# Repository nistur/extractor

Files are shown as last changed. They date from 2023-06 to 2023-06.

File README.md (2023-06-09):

Extractor
=========

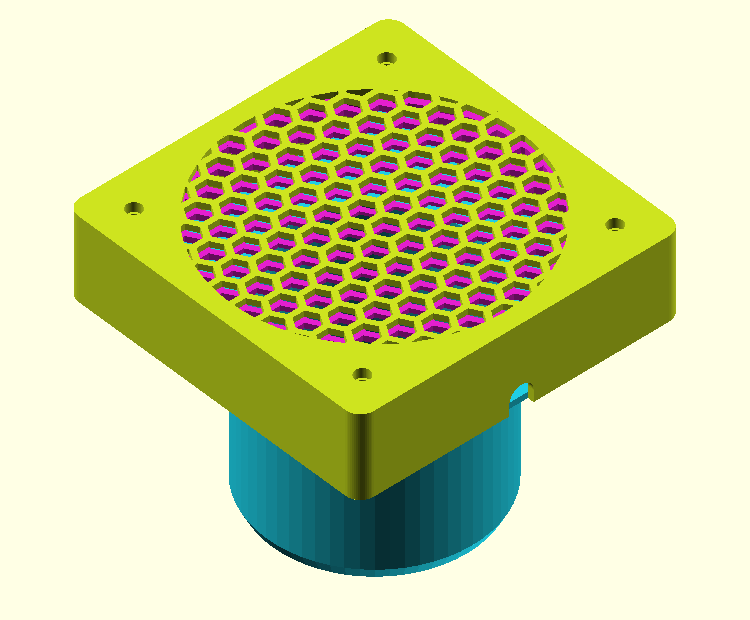
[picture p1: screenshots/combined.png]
Extractor Fan Enclosure


I have an enclosure for my 3D printer, but it still smells, I want to be able to safely vent this outside. I have a bunch of 120mm PC fans around, and a 12V power supply, so I thought I'd quickly make an enclosure to hold this, and connect to an exhaust pipe made from a drain pipe.

The enclosure is being designed to be used with a 120x25mm PC style fan, and a 90mm ID pipe for exhaust. It has space for a carbon filter to be cut and put at the front. All dimensions should be in modifiable in params.scad for other size parts. I have not added a HEPA filter at this point because everything I can find is a specific size for a specific vacuum cleaner etc, and not a simple cut-the-right-size filter sheet like a carbon filter. Assuming this works, I will look for a solution for this.

All models are created in modules/mod_{MODULE}.scad and then are imported into {MODULE}.scad for exporting as STL in the correct orientation. A Makefile is provided for easy export on Linux. To see the extractor built, preview.scad has been provided with the parts in the correct position.

NOTE: This model is incomplete and has not been test printed yet. It is also still final measurement/confirmation on all dimensions.

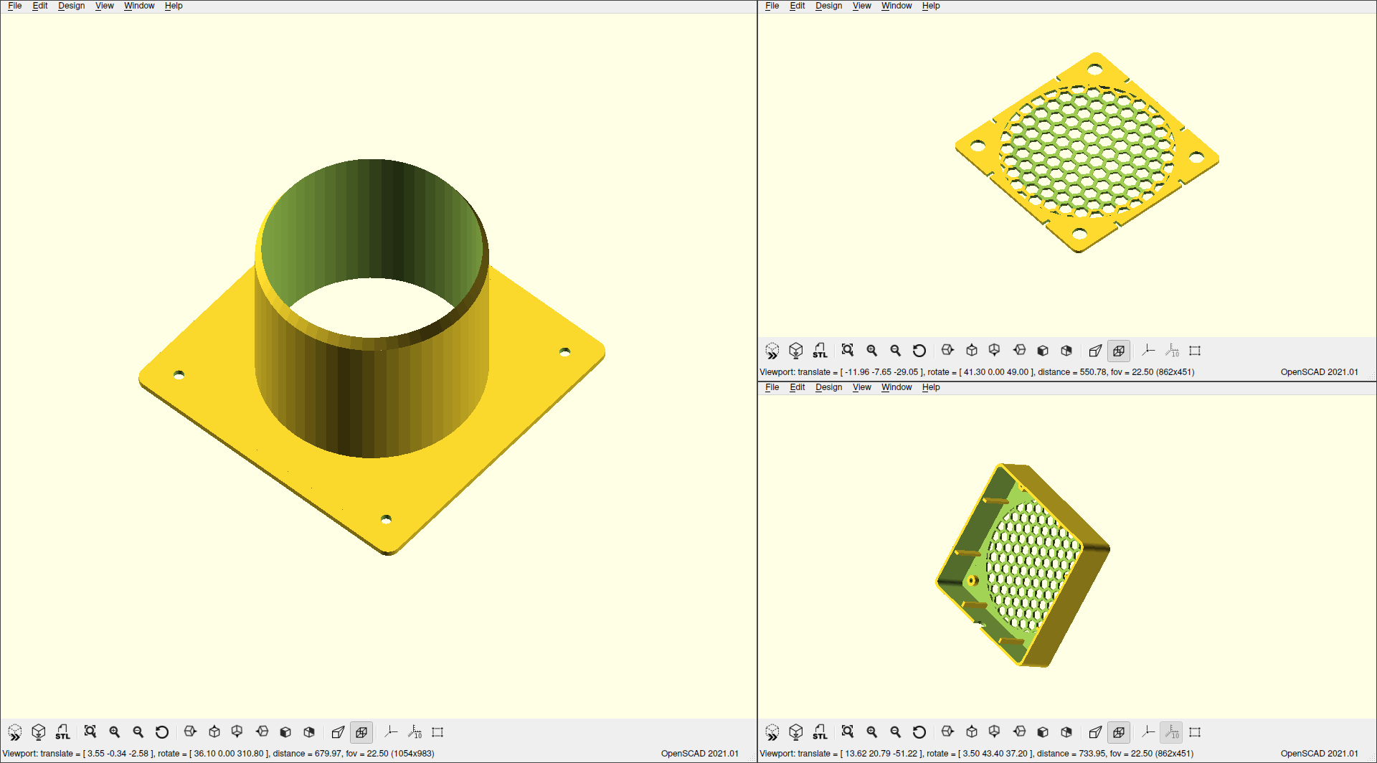
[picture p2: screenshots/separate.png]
Parts


To mount this, the intention is to cut/drill a 100mm diameter hole in the enclosure, and then insert threaded inserts into the enclosure (or tap if the enclosure can take machine threads) based on the hole pattern for the fan used, in the case of a 120mm fan, this is 105mm apart. Then a long screw is interted through all parts, sandwiching a carbon filter between the enclosure and the filterguard, with the slightly concave side facing the fan. The screws are then only screwed into the threaded inserts and not into the printed parts, reducing wear on those parts. A suitable exhaust pipe is then fitted over the connector which should be protruding out of the hole.

I have also created an "exhaust" part, which is a matching part that I will be attaching the where it will be finally exhausting outside. This is similar to the "connector" part, but with the opposite type connector (ie it goes over a 90mm pipe rather than inside an end piece) and includes a grille to keep out leaves or whatever happens to be trying to get in.

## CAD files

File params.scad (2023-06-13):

/*
 * Copyright (c) 2023 Philipp Geyer
 *
 * This software is provided 'as-is', without any express or implied warranty. In no
 * event will the authors be held liable for any damages arising from the use of this
 * software.
 *
 * Permission is granted to anyone to use this software for any purpose, including
 * commercial applications, and to alter it and redistribute it freely, subject to the
 * following restrictions:
 *
 * 1. The origin of this software must not be misrepresented; you must not claim
 *    that you wrote the original software. If you use this software in a product,
 *    an acknowledgment in the product documentation would be appreciated
 *    but is not required.
 * 2. Altered source versions must be plainly marked as such, and must not be
 *    misrepresented as being the original software.
 * 3. This notice may not be removed or altered from any source distribution.
 *
 * Philipp Geyer
 * nistur@gmail.com
 */

// Size of the fan - This is the outside dimentions, and assumes a square. For a standard PC fan,
// this is correct at 120mm
fan_size=120;

// Thickness of the fan. This is dependant on the make and model fan you have. Could be 25mm, 38mm etc
fan_thickness=25;

// Thickness of the carbon filter - this is currently including one `thickness` below to account for the
// guard piece. I didn't want to split this up, as I was considering the guard and the filter as one unit
filter_thickness=5;

// Space around the fan for routing wires etc
padding=5;

// How curvy do we want this. 5mm gives a nice look
corner_radius=5;

// Thickness of the walls of the enclosure.
thickness=2.5;

// Inside diameter of the connector - this is not critical as it doesn't interface with anything (yet) however does
// implicitly define the outer diameter of the exhaust sleeve, which keeps the same wall thickness as the connector.
// Note: Should this be entirely derived from `thickness`? It would currently work out to be the same, but originally
// kept separate so that I could make the connector wall thicker if I needed more strength.
connector_id=85;

// Outside diameter of the connector - This is important as it interfaces with the inside of the pipe
connector_od=90;

// Length of the connector - how much is able to fit inside the exhaust pipe
connector_length=80;

// How long a taper we want to put on the top of the connector, to allow for easier fitting
connector_taperlength=10;

// How much the taper should cut in by
connector_taperamount=5;

// Length of the exhaust pipe. Mirrors `connector_length` above but kept separate as it is probably
// desirable to be different
exhaust_length=50;

// Diameter of screws used to mount this. I wanted to use M4, but added a bit of extra space, as I didn't want it to
// thread into the plastic at all, and wanted some wiggle room for my inevitably bad threaded insert mounting.
screw_diameter=4.3;

// Separation of screws - this is defined on the fan size, it assumes a square screw pattern. For 120mm fans, 105mm
// is standardised
screw_separation=105;

// diameter of screw posts - these hold the fan in, and guide the filter guard
screwpost_diameter=10;

// diameter of the screw heads. I'm using 7mm cap heads, so adding a bit extra space
screwhead_diameter=7.2;

// Depth of cutout for the screw heads. If using non-cap heads, can have shallower holes
screwhead_depth=4;

// Size of hexes in the grilles
hex_size=10;

// Space between hexes in the grilled
hex_spacing=1;

// Size of cutout on one side to allow for cables
cablecutout_diameter=10;

// Clearance between plastic-plastic parts. Things like screws do not respect this, as it may be desirable to
// tweak their fit manually
clearance=0.2;

$fn = $preview ? 60 : 360;

// size is:
// + size of the fan
// + some padding around the outside for routing cables
// - Some clearance to let the enclosure fit on top
base_size=fan_size+(padding*2)-(clearance*2);

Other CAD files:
connector.scad
enclosure.scad
exhaust.scad
filterguard.scad
modules/mod_connector.scad
modules/mod_enclosure.scad
modules/mod_exhaust.scad
modules/mod_fan.scad
modules/mod_filterguard.scad
preview.scad

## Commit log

2023-06-07 First commit of extractor enclosure
    Still missing a couple of features, mostly a cutout for the fan cable
    to come out, and a recess for the screw heads
    [connector.scad, enclosure.scad, filterguard.scad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]
2023-06-07 Missing features - screw head recess, cable cutout, fan guide rails
    Also fixing broken hex grid positioning calculation
    Adding screenshots
    [mod_enclosure.scad, mod_filterguard.scad, params.scad]
2023-06-09 Adding exaust, variation of the connector which will connect outside
    [exhaust.scad, mod_exhaust.scad, preview.scad]
2023-06-09 Cleanup
    Adding comments
    Fixing namespacing issues (adding prefixes to limit clashes)
    Updating README
    [mod_connector.scad, mod_enclosure.scad, mod_exhaust.scad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]
2023-06-13 Updating clearances
    My print was a little tighter than I intended, and a lot tighter in
    some places. So I've increased all clearances, and improved some areas
    that didn't provide decent setup.
    [exhaust.scad, mod_connector.scad, mod_enclosure.scad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]
